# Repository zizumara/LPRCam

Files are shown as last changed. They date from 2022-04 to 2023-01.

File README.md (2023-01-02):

# LPRCam
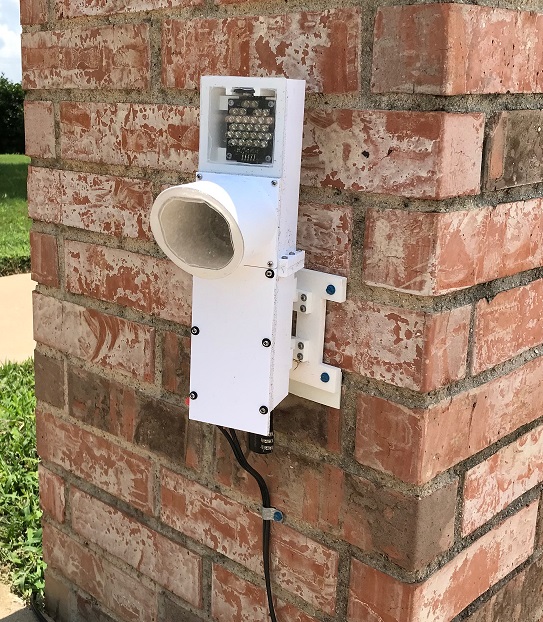
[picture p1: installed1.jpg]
Installed Camera


(2022-06-06 NOTE: UCTronics has modified the design of the Arducam 12.3 MP HQ camera with automatic IR-cut filter.  The new design requires the Bullseye O/S to be used, and the IR-cut filter interface now works differently.  Unfortunately, there isn't a distribution of openalpr for Bullseye.  You may be able to special order the older version of the camera from Arducam and continue to use Buster.  If anyone can figure out how to get this project updated for Bullseye, I'd like to hear from them.)

This project includes the software and hardware design for a DIY motion-activated Raspberry Pi security camera.  The Linux Motion application is used to detect motion and capture images.  The following hardware is used for this project:
* Raspberry Pi Zero W running Buster O/S
* Pi Zero W 6" camera ribbon cable (Amazon)
* Raspberry Pi 4 (for web server)
* Arducam 12.3 MP HQ camera with automatic IR-cut filter (www.arducam.com) -- photocell removed
* Arducam 12mm CS-Mount Lens with Manual Focus and Adjustable Aperture (Amazon)
* A custom IR illuminator (KiCAD files included)
* A custom ambient light sensor (KiCAD files included)
* A 3D-printable enclosure (STL files included) -- use white PETG filament
* A 5V 2.5A step-down voltage regulator (Pololu #2858)
* 2.1mm DC panel mount barrel jack (Adafruit #610) and plug
* CESFONJER Mini Locking Toggle Switch (Amazon)
* GIVERARE Combination Travel Cable Lock (Amazon)
* DEWENWILS 60W Outdoor Low Voltage Transformer (Amazon)
* Woods 55213143 16/2 Low Voltage Lighting Cable, 100-Feet (Amazon)
* Red and green LEDs with 330 Ohm current limiting resistors
* 26 AWG wiring with various Dupont connectors (KiCAD files included)
* Clear Lexan sheet 0.08x7.6x11 inch or similar dimensions (Amazon)
* Clear silicone waterproof sealant (Amazon)
* Silicone modified conformal coating (Amazon)
* 22 #3-48x1/2" steel screws (Fastenal or McMaster-Carr)
* 12 #3-48x1/16" steel screws  (Fastenal or McMaster-Carr)
* Microchip Pickit 4 programmer (for programming the custom light sensor)
* (Optional) Wireless Access Point (Amazon)

For nighttime operation, when the ambient light sensor registers light below a configured level, software enables the IR illuminator and switches in the IR-cut filter on the camera module.  The light level is used to select one of three different Motion configuration files which have mmalcam_control_params settings appropriate for daytime, twilight, and nighttime operation, respectively.  The light level is a time-averaged reading for which the width of the sampling window may be adjusted via the sensor I2C interface.

The camera box should be printed with white PETG filament to resist outdoor heat as well as heat generated by the IR illuminator and Pi Zero W.  All parts of the box should be given four coats of silicone modified conformal coating, both inside and out.  (WARNING: silicone modified conformal coating must be applied in an area with good ventilation.)  The Lexan covers for the camera shroud and IR array opening must be cut to fit from the Lexan sheet.  All seams must be filled with silicone sealant to produce a waterproof enclosure, including around the power jack.

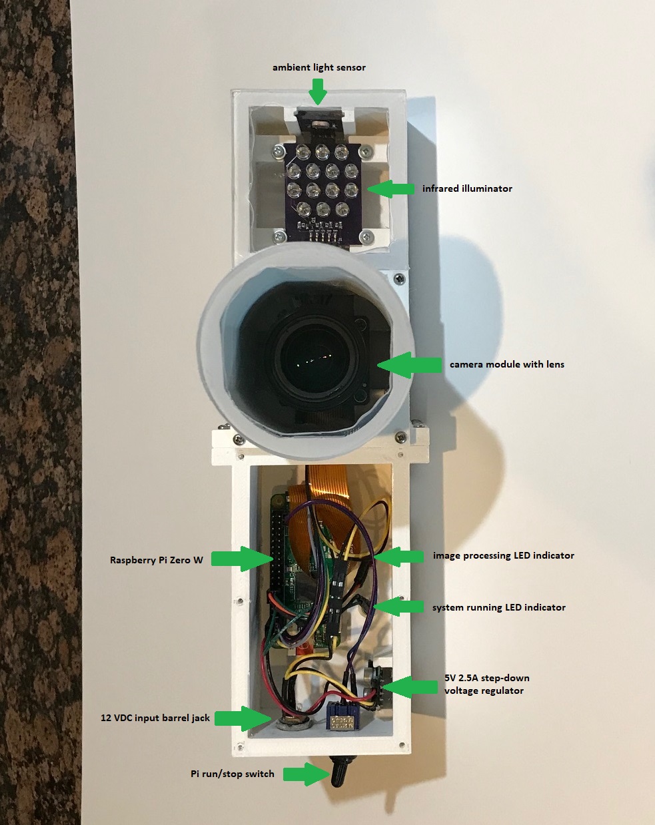
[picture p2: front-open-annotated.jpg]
Camera Box Interior


# Web Server

The files included in the /web directory provide everything needed to create a web server for reviewing captured images and license plate numbers.  The web server runs on a separate Raspberry Pi 4B.  If the web server is to be accessible from the Internet, it is strongly recommended that the security hardening procedures be followed in setup.txt.

During operation, captured files are periodically copied from the Pi Zero W to the web server via rsync.  A wireless access point may be needed if the camera box is not close to your wireless router.  The web server performs the CPU-intensive analysis of the captured images using OpenALPR to detect and read license plates.  The results are displayed on the web page, an example of which is shown below (for security reasons, plate numbers and actual camera location are blanked out in grey).

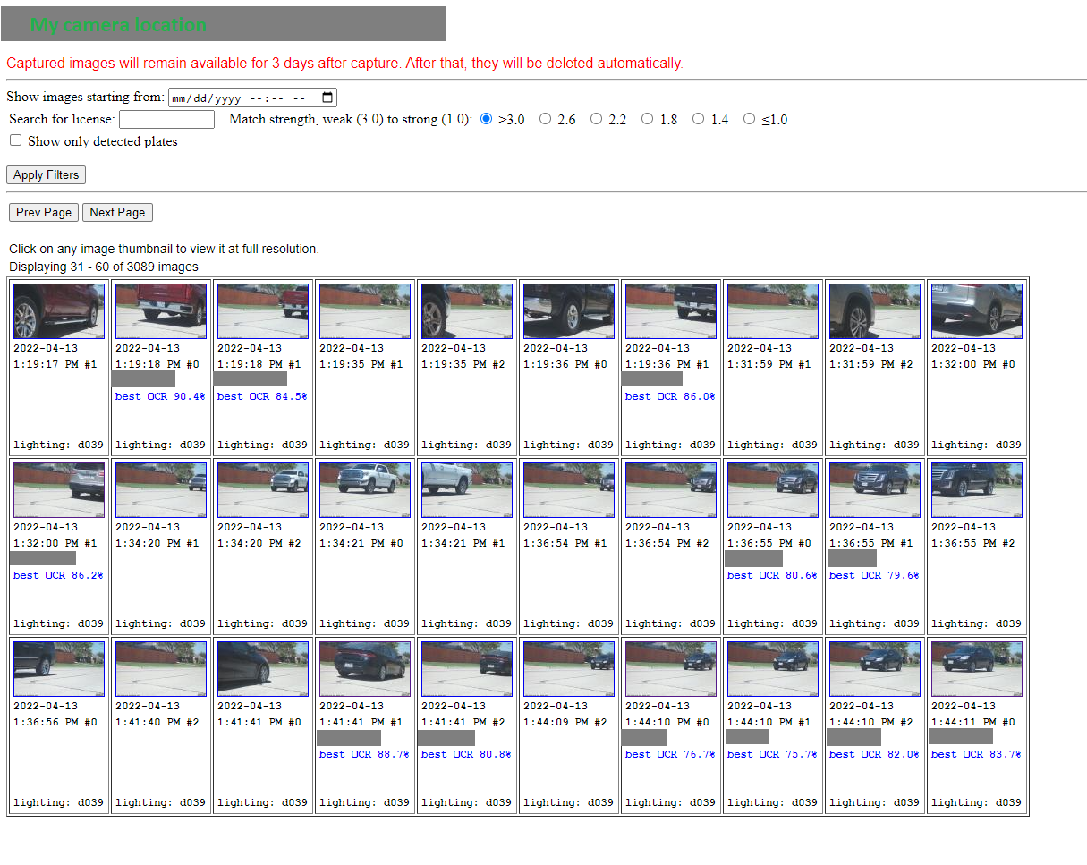
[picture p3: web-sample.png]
Web Page


For each captured image, a thumbnail is displayed with the date and time of capture and the lighting level at the bottom in format s###, where s is 'd' for day, 't' for day-twilight, 'u' for night-twilight, and 
'n' for night, and the 3-digit number represents the value read from the light sensor.  If a plate is detected by OpenALPR, the highest confidence plate number result is displayed below the capture date, along with the best confidence level of the optical character recognition (OCR) algorithm (0-100%).  A question mark (?) follows the plate number as a signal that this is the best guess by OpenALPR.  Users may click on any thumbnail to display the full resolution image on a new page.  On this page, the user may enter the actual license plate number so that it may be displayed on the main page in green followed by the text "** verified **".

The top of the main page has a filter section which may be used to limit the number of images displayed.

* Starting date: By default, all captured images are displayed regardless of capture date.  Setting the date and clicking Apply Filters can be used to limit the list to more recent images.
* Search for license: Enter license plate text in this box and click Apply Filters to find OpenALPR results similar to the text supplied.  Use the match strength radio buttons to set how close the match must be to the supplied text.
* Show only detected plates: Check this box and click Apply Filters to display only images for which OpenALPR has found a license plate.

The license plate search algorithm is optimized using OCR statistics gathered from hundreds of prior OpenALPR results that were each manually verified on the view full image page.  Entries made here are added to the OpenALPR .json files in the results directory.  Certain characters like 'B' may be misinterpreted by the OCR engine as '8', or 'D' may be misinterpreted as '4'.  Some characters, like 'I' may not be present at all on any license plate, but might be misidentified from a '1' or from an edge on the license plate.  The genalprstats.py module analyzes the contents of the results directory to determine the frequency at which characters are correctly or incorrectly identified.  The results of this analysis are stored in ocrstats.pickle and applied when the user performs a license plate search using a modified Wagner-Fischer algorithm to find the Levenshtein distance between the plate number entered and the plate numbers returned by OpenALPR.

The Levenshtein distance is defined as the smallest number of 1-character substitutions to convert one string into another.  The modifications to the Wagner-Fischer algorithm allow for the substitution value (normally 1) to be less than one depending on the frequency at which the OCR engine makes an error for the particular substitution. This modified Levenshtein distance can be set as the threshold to count an OpenALPR result as as match when performing a search.  The threshold for the search can be set using the radio buttons at the top of the main web page.  A modified Levenshtein distance of 3.0 or greater signifies a "weak" match, while a modified Levenshtein distance of 1.0 or less represents a "stong" match.

The ocrstats.pickle file in this archive are specific to the location at which testing was originally performed.  This may not be suitable for a different location, in which case a new file might be generated.  However, keep in mind that this requires a large number of plates to be manually verified to generate sufficient data for the analysis.  The existing ocrstats.pickle file was generated from approximately 1,000 analyzed plates, and a similar number is recommended for a new analysis.

# Performance

The following factors are the most significant in their effect on the performance of this system.

* Motion frame rate: The Motion application can capture about 1 to 2 frames per second under the given configuration.  This depends on image size and the processing power of the Raspberry Pi Zero W.  The current frame rate appears to be suitable for capturing at least one image of a license plate on a moving vehicle under most conditions.  The frame rate could be increased by reducing the image size or replacing the Pi Zero W with a Pi Zero 2 W.  However, increasing the rate at which images are captured may be detrimental to other performance factors.
* Image capture rate: The Motion application may experience false positives for detecting motion due to changing lighting conditions.  In particular, windy, partly cloudy days often produce hundreds or even thousands of additional images per day, as the changing cloud shadows often cause significant numbers of pixels in the image to change intensity.  The threshold parameter in motion_day.conf sets the number of changed pixels to trigger motion capture.
* Image transfer rate: Images are periodically transferred from the camera system to the web server for OpenALPR analysis using rsync.  If the image capture rate is large for an extended period, this can generate a large backlog of images to transfer, depending on the configured number of days to keep images in LPRCam.conf.  The result may be that the web server gets behind by several hours in analyzing images.  To reduce the number of image files to be synchronized, keep the number of days to keep files in LPRCam.conf low (no more than 1.0 days).  Note that the web server will keep images for three days, which is hardcoded in LPRserver.py.  The rsync bwlimit parameter is also hardcoded in LPRserver.py at 400 kbps to avoid overloading the wireless network, but may be increased or eliminated.
* ALPR masks: A portion of each image may be excluded from analysis by the OpenALPR application to reduce processing time for each image as defined by mask files.  Two mask files are provided in this archive, alpr-mask-1600x960.jpg and alpr-mask-800x480.jpg, which mask out the lower portion of the image where license plates are not expected to be found.  It may be necessary to replace or exclude these files.  Note that if renamed or excluded, the configuration files openalpr.defaults.1600x960 and openalpr.defaults.800x480 must be updated.
* ALPR processing: OpenALPR consumes considerable CPU resources in analyzing each image, which can result in a significant processing backlog.  Performance can be improved by reducing image dimensions.  Note that this must be done for all the motion configuration files and the OpenALPR mask files.

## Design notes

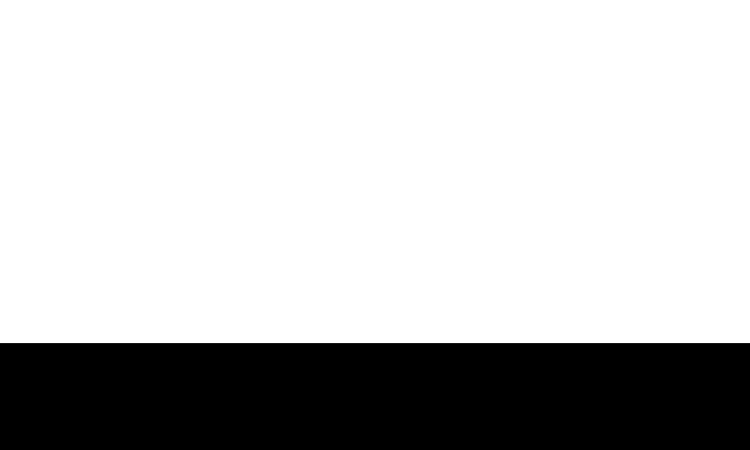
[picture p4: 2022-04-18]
web/openalpr-config/alpr-mask-800x480.jpg

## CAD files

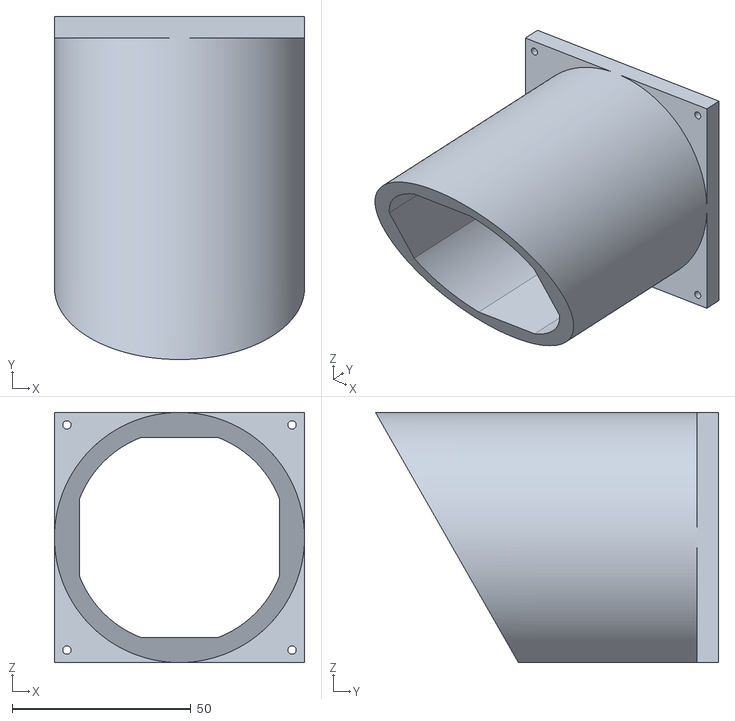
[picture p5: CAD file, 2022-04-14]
3D-printable-enclosure/camera shroud cyl.stl
70.0 x 96.0 x 70.0

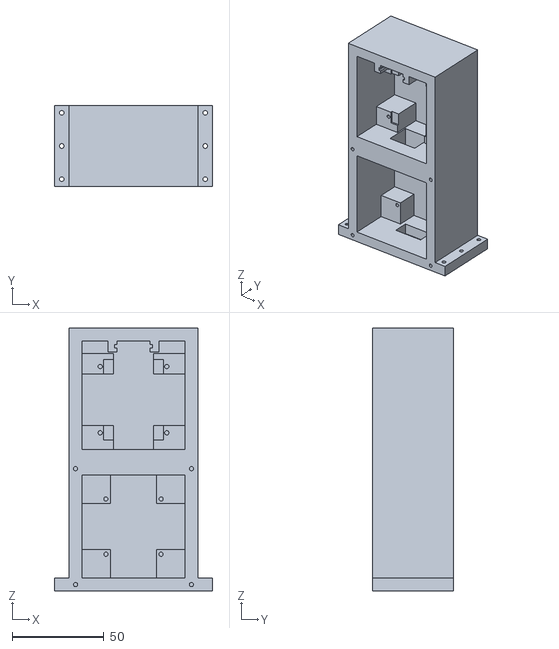
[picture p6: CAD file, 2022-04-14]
3D-printable-enclosure/camera box.stl
86.0 x 44.0 x 143.0

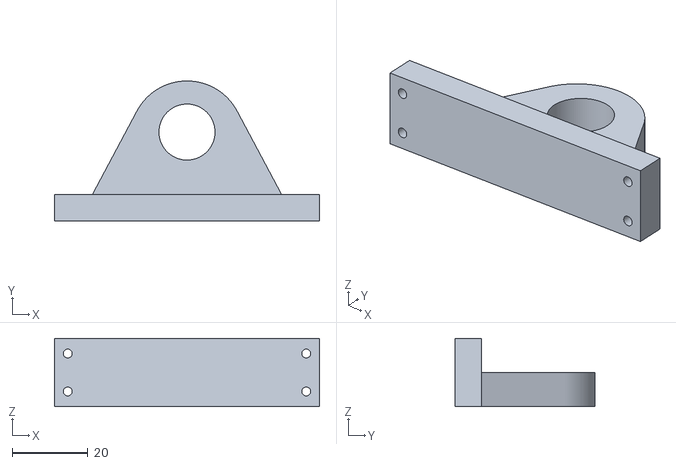
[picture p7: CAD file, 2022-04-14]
3D-printable-enclosure/CPU box mount.stl
70.0 x 37.0 x 18.0

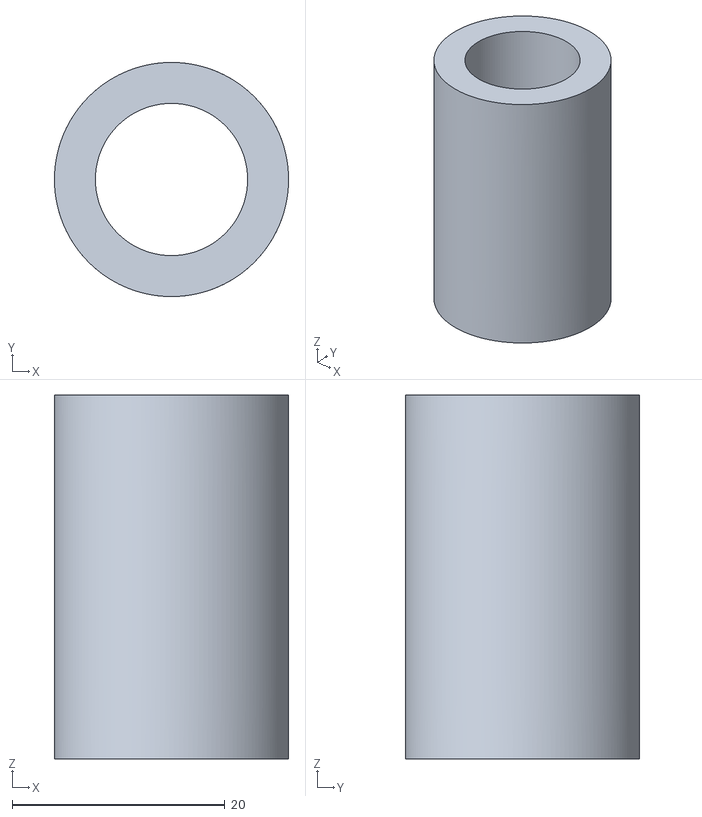
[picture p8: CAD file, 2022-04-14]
3D-printable-enclosure/mount sleeve.stl
22.0 x 22.0 x 34.2

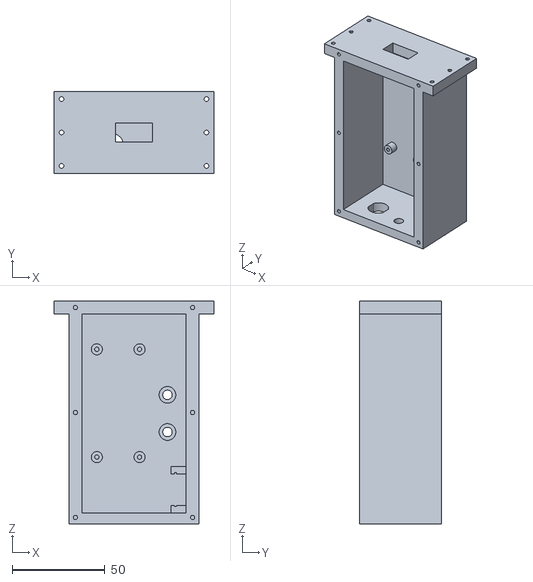
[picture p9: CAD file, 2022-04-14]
3D-printable-enclosure/CPU box.stl
86.0 x 44.0 x 120.0

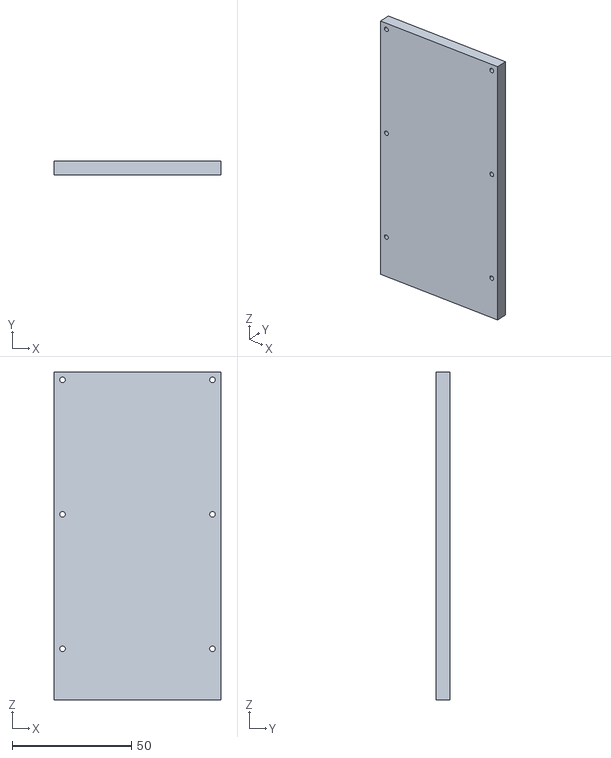
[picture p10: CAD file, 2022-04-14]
3D-printable-enclosure/CPU box cover.stl
70.0 x 6.00 x 137.8

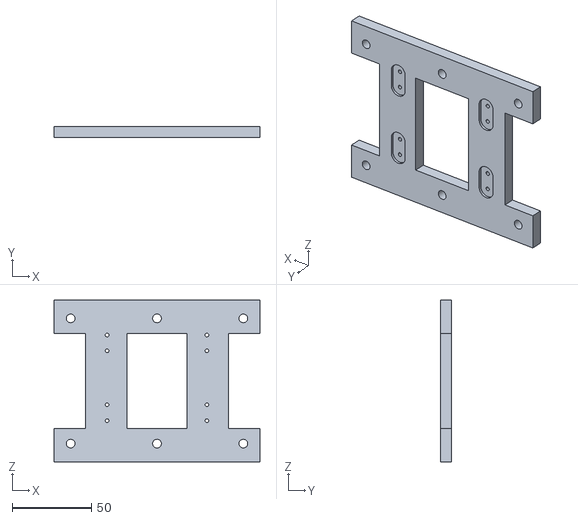
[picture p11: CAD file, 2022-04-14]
3D-printable-enclosure/base mount.stl
130.0 x 7.00 x 102.0

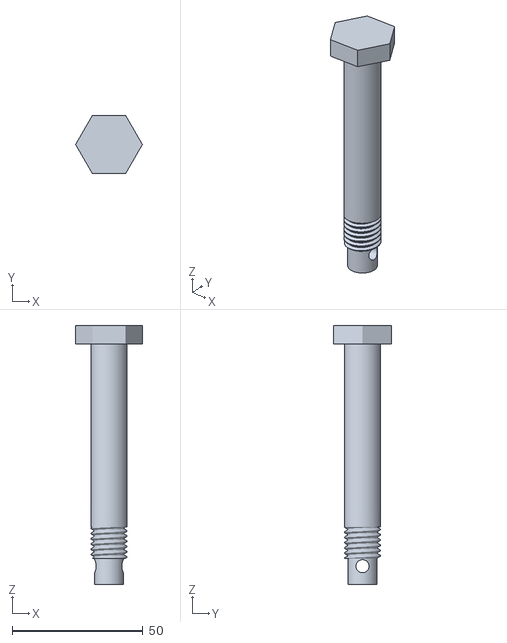
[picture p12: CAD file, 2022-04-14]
3D-printable-enclosure/mount bolt.stl
25.6 x 22.1 x 99.0

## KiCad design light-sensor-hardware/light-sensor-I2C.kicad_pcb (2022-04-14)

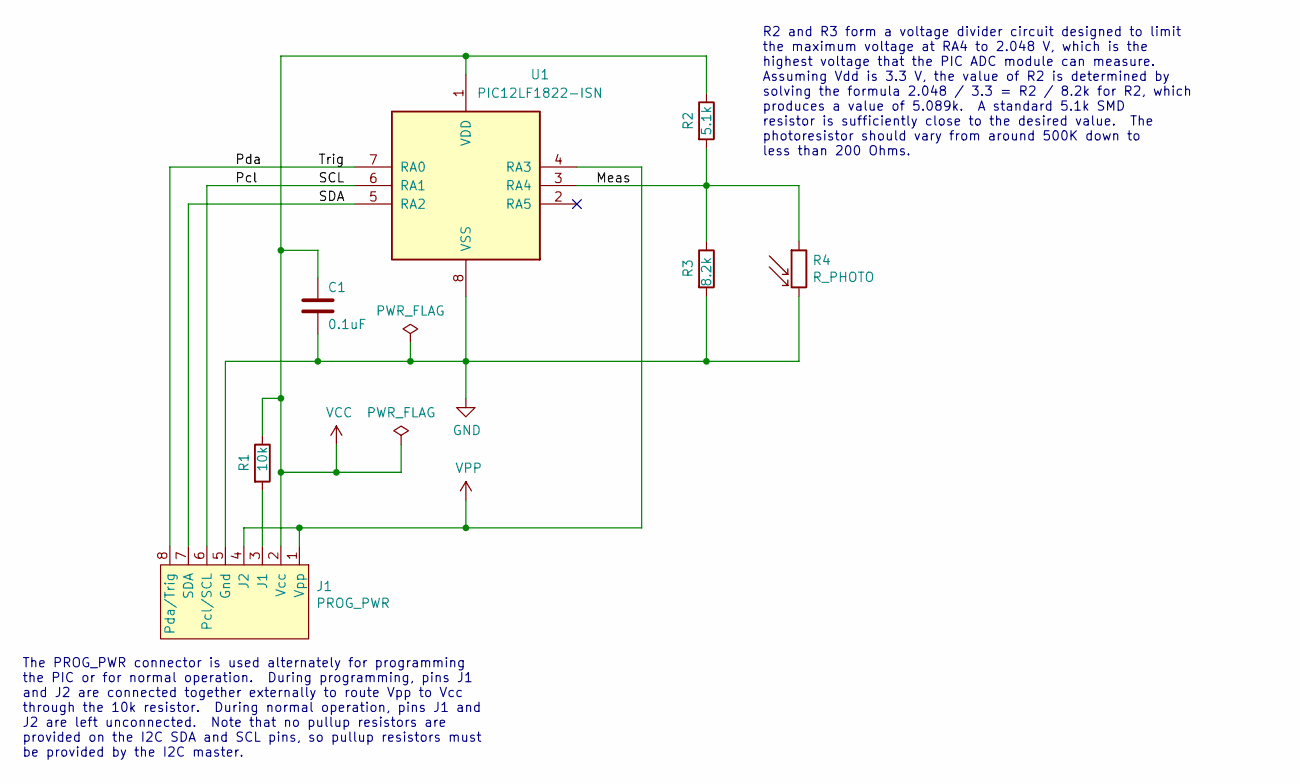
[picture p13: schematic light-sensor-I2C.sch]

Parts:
C1: 0.1uF; C_0805_2012Metric_Pad1.15x1.40mm_HandSolder
J1: PROG_PWR; PinSocket_2x04_P2.54mm_Horizontal
R1: 10k; R_0805_2012Metric_Pad1.15x1.40mm_HandSolder
R2: 5.1k; R_0805_2012Metric_Pad1.15x1.40mm_HandSolder
R3: 8.2k; R_0805_2012Metric_Pad1.15x1.40mm_HandSolder
R4: R_PHOTO; R_LDR_7x6mm_P5.1mm_Vertical
U1: PIC12LF1822-ISN; pic12lf1822-i&slash_sn

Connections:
/Meas: R2.2, R3.1, R4.1, U1.3 (RA4)
/Pcl: J1.6 (Pcl/SCL), U1.6 (RA1)
/Pda: J1.8 (Pda/Trig), U1.7 (RA0)
/SDA: J1.7 (SDA), U1.5 (RA2)
GND: C1.2, J1.5 (Gnd), R3.2, R4.2, U1.8 (VSS)
unnamed: J1.3 (J1), R1.2
VCC: C1.1, J1.2 (Vcc), R1.1, R2.1, U1.1 (VDD)
VPP: J1.1 (Vpp), J1.4 (J2), U1.4 (RA3)

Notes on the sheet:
R2 and R3 form a voltage divider circuit designed to limit the maximum voltage at RA4 to 2.048 V, which is the highest voltage that the PIC ADC module can measure. Assuming Vdd is 3.3 V, the value of R2 is determined by solving the formula 2.048 / 3.3 = R2 / 8.2k for R2, which produces a value of 5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
The PROG_PWR connector is used alternately for programming the PIC or for normal operation. During programming, pins J1 and J2 are connected together externally to route Vpp to Vcc through the 10k resistor. During normal operation, pins J1 and J2 are left unconnected. Note that no pullup resistors 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

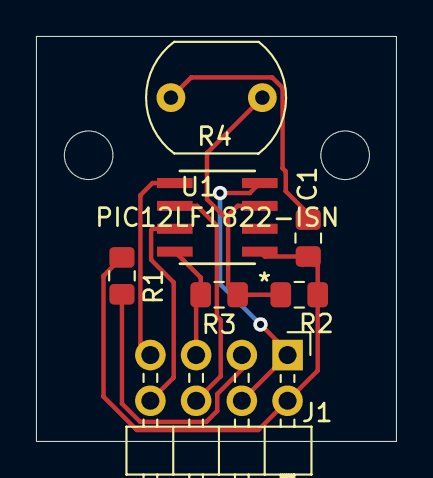
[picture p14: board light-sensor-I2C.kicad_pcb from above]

Board: 2 copper layers, 20.0 x 22.5 mm, 7 parts (0 on the bottom side), 8 nets.

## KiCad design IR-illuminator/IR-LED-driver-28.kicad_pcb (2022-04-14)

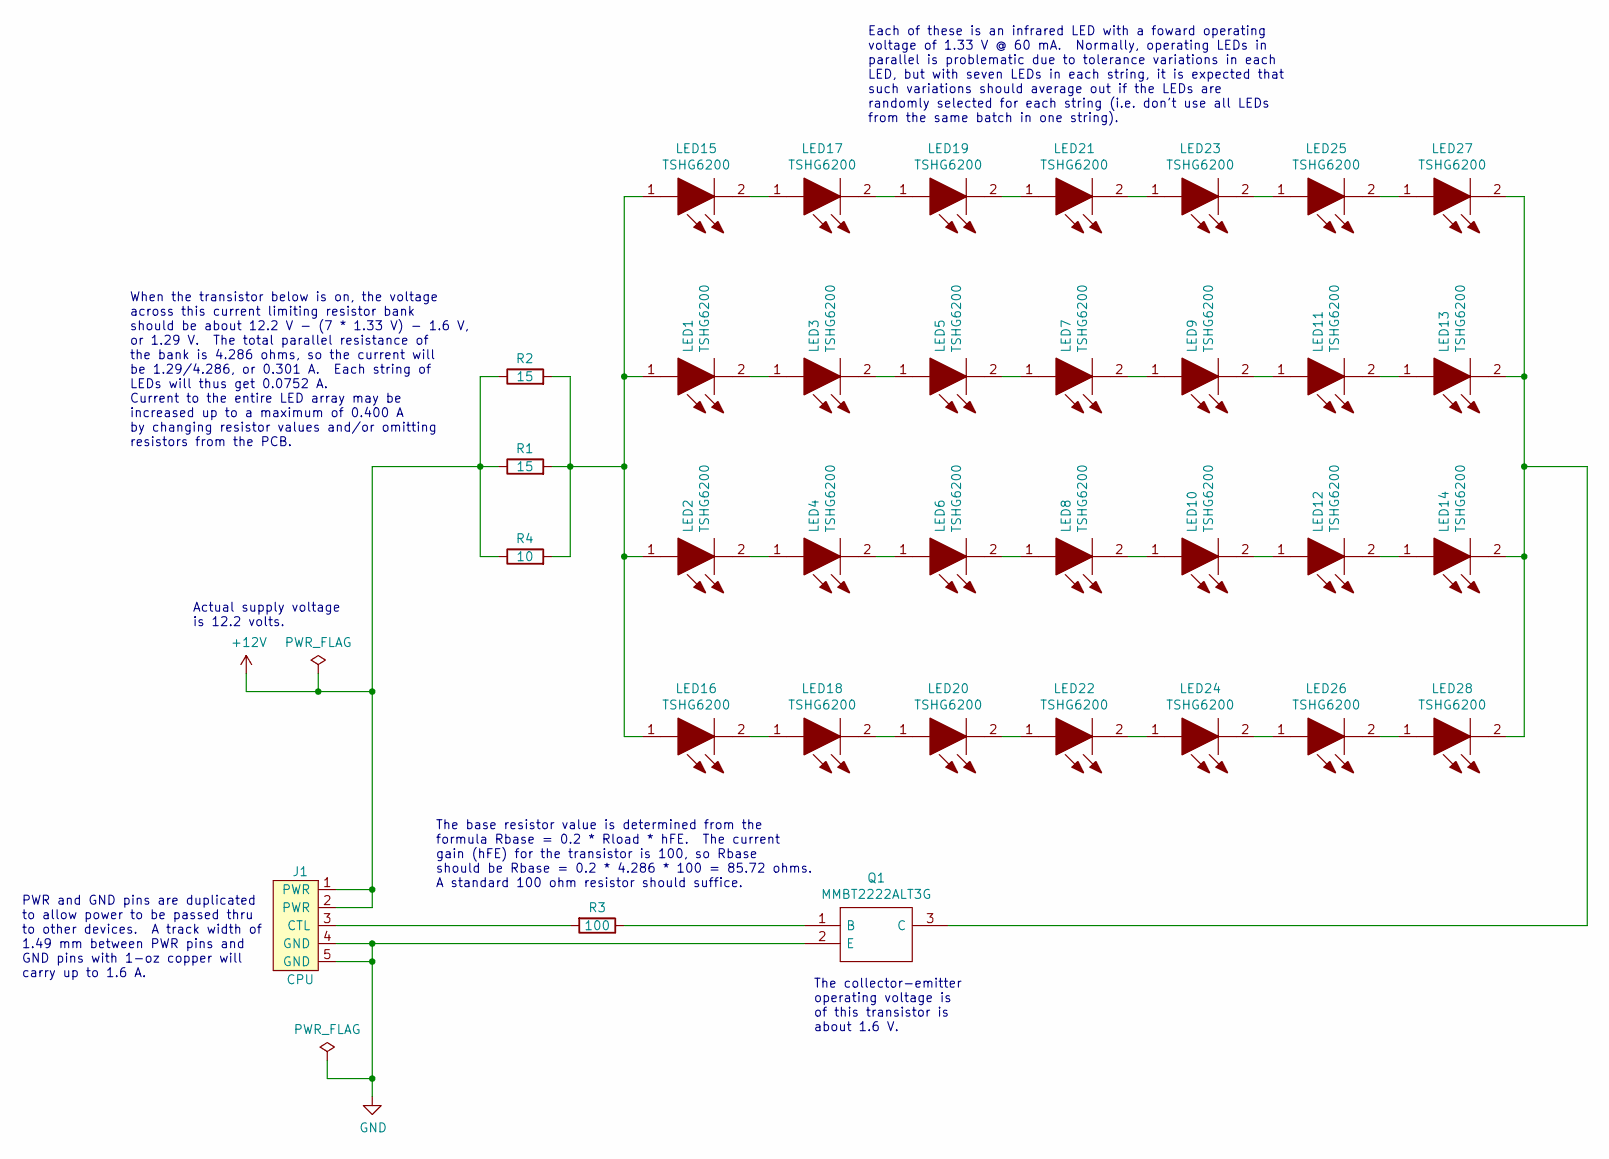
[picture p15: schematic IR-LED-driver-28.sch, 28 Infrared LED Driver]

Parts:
J1: CPU; PinHeader_1x05_P2.54mm_Horiz_SMD
LED1, LED2, LED3, LED4, LED5, LED6, LED7, LED8, LED9, LED10, LED11, LED12, LED13, LED14, LED15, LED16, LED17, LED18, LED19, LED20, LED21, LED22, LED23, LED24, LED25, LED26, LED27, LED28: TSHG6200; Mouser Part Number 782-TSHG6200
Q1: MMBT2222ALT3G; SOT96P237X111-3N; Mouser Part Number 863-MMBT2222ALT3G
R1, R2: 15; R_0805_2012Metric_Pad1.15x1.40mm_HandSolder
R3: 100; R_0805_2012Metric_Pad1.15x1.40mm_HandSolder
R4: 10; R_0805_2012Metric_Pad1.15x1.40mm_HandSolder

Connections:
+12V: J1.1 (PWR), J1.2 (PWR), R1.1, R2.1, R4.1
GND: J1.4 (GND), J1.5 (GND), Q1.2 (E)
unnamed: J1.3 (CTL), R3.2
unnamed: LED1.1, LED2.1, LED15.1, LED16.1, R1.2, R2.2, R4.2
unnamed: LED1.2, LED3.1
unnamed: LED2.2, LED4.1
unnamed: LED3.2, LED5.1
unnamed: LED4.2, LED6.1
unnamed: LED5.2, LED7.1
unnamed: LED6.2, LED8.1
unnamed: LED7.2, LED9.1
unnamed: LED8.2, LED10.1
unnamed: LED10.2, LED12.1
unnamed: LED9.2, LED11.1
unnamed: LED11.2, LED13.1
unnamed: LED12.2, LED14.1
unnamed: LED13.2, LED14.2, LED27.2, LED28.2, Q1.3 (C)
unnamed: LED15.2, LED17.1
unnamed: LED16.2, LED18.1
unnamed: LED17.2, LED19.1
unnamed: LED18.2, LED20.1
unnamed: LED19.2, LED21.1
unnamed: LED20.2, LED22.1
unnamed: LED21.2, LED23.1
unnamed: LED22.2, LED24.1
unnamed: LED23.2, LED25.1
unnamed: LED24.2, LED26.1
unnamed: LED25.2, LED27.1
unnamed: LED26.2, LED28.1
unnamed: Q1.1 (B), R3.1

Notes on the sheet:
The collector-emitter operating voltage is of this transistor is about 1.6 V.
Each of these is an infrared LED with a foward operating voltage of 1.33 V @ 60 mA. Normally, operating LEDs in parallel is problematic due to tolerance variations in each LED, but with seven LEDs in each string, it is expected that such variations should average out if the LEDs are randomly select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
When the transistor below is on, the voltage across this current limiting resistor bank should be about 12.2 V - (7 * 1.33 V) - 1.6 V, or 1.29 V. The total parallel resistance of the bank is 4.286 ohms, so the current will be 1.29/4.286, or 0.301 A. Each string of LEDs will thus get 0.0752 A. Curre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
Actual supply voltage is 12.2 volts.
The base resistor value is determined from the formula Rbase = 0.2 * Rload * hFE. The current gain (hFE) for the transistor is 100, so Rbase should be Rbase = 0.2 * 4.286 * 100 = 85.72 ohms. A standard 100 ohm resistor should suffice.
PWR and GND pins are duplicated to allow power to be passed thru to other devices. A track width of 1.49 mm between PWR pins and GND pins with 1-oz copper will carry up to 1.6 A.

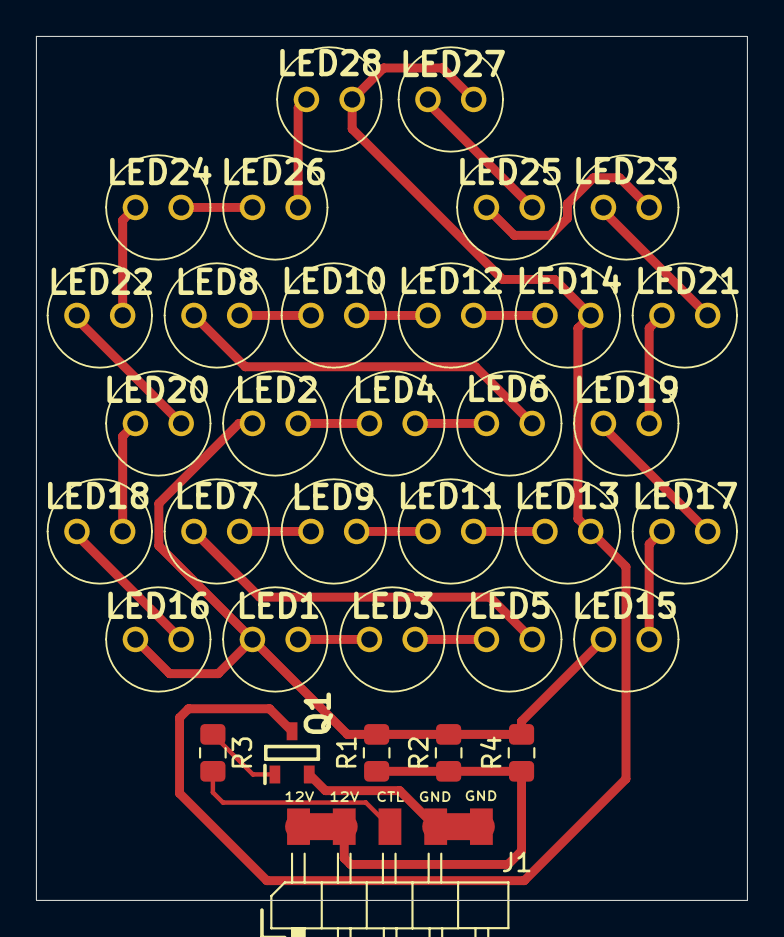
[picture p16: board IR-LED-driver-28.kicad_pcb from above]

Board: 2 copper layers, 39.5 x 48.0 mm, 34 parts (0 on the bottom side), 30 nets.

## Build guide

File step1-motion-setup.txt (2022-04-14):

This setup was copied from https://pimylifeup.com/raspberry-pi-webcam-server/comment-page-1/ and modified
specifically for still image capture only.

Update the Pi O/S:

   sudo apt-get update
   sudo apt-get upgrade

For convenient access from Windows via Remote Desktop, install xrdp:

   sudo apt-get install xrdp

(or install PuTTY to access the Pi command line only)

Connect the Pi camera and enable it via the desktop preferences menu or use the following:

   sudo raspi-config

Add the Pi camera as a v4l2 device to modules:

   sudo modprobe bcm2835-v4l2

(An alternate technique is to add bcm2835-v4l2 at the bottom of the /etc/modules file.)

Reboot the Pi for the above changes to take effect:

   sudo reboot

Install the packages needed by Motion:

   sudo apt install autoconf automake build-essential pkgconf libtool git libzip-dev libjpeg-dev gettext libmicrohttpd-dev 
      libavformat-dev libavcodec-dev libavutil-dev libswscale-dev libavdevice-dev default-libmysqlclient-dev libpq-dev 
      libsqlite3-dev libwebp-dev

Get the Motion deb file for Raspian Buster from GitHub and install it:

   sudo wget https://github.com/Motion-Project/motion/releases/download/release-4.3.1/pi_buster_motion_4.3.1-1_armhf.deb
   sudo dpkg -i pi_buster_motion_4.3.1-1_armhf.deb

Create and configure directories for pictures and movies:

   sudo mkdir /motion
   sudo chgrp motion /motion
   sudo chmod a+rwx /motion

Configure Motion (see motion-configuration.txt; use /motion as target_dir).

Disable the Motion daemon by editing /etc/default/motion and setting start_motion_daemon=no

Run the motion application:

   motion -c /etc/motion/motion.conf

Upon motion detection, the captured images will be stored in the /motion directory.  This directory needs to be 
purged periodically to prevent from consuming all disk space.  Application logging is directed to stderr.

RUNNING IN DAEMON MODE

The application can also be run automatically in daemon mode at boot up by setting start_motion_daemon=no in 
/etc/default/motion and setting daemon on in /etc/motion/motion.conf.  Whenever making changes to motion.conf, 
the service must be restarted as follows:

   sudo service motion restart

The motion service can be stopped using the following:

   sudo service motion stop

To determine if the motion service is running, use

   sudo service --status-all

and verify that motion is preceded by '[+]'.  If the service is not running, this will be '[-]'.

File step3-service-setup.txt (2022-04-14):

LPRCam Service Installation Instructions

These instructions assume that LPRCam.py is located in /home/pi/projects/LPRCam.

1. Copy LPRCam.sh to directory /usr/local/bin.

2. Make sure LPRCam.sh is executable with

      sudo chmod 755 /usr/local/bin/LPRCam.sh

3. Copy LPRCam.service to directory /lib/systemd/system.

4. Use the following to enable the service on startup.

      sudo systemctl enable LPRCam
      
5. To check status after startup, use

      sudo systemctl status LPRCam
   
   This should display status showing that LPRCam.service is loaded and 
   the status is "active (running)".

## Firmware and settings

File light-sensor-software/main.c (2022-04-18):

/*******************************************************************************
 * Light Sensor with I2C Interface
 * Created May 9, 2021
 * 
 * Overview:
 * This program runs on a PIC12LF1822 MCU and takes regular ADC samples of the
 * voltage across a CdS photocell, providing the readings across an I2C 
 * interface.  The circuit is designed such that complete darkness reads as
 * near the maximum ADC voltage of 2.048V and full brightness reads near 0V
 * (corresponding to 10-bit values of 1023 and 0, respectively).  The readings
 * are averaged on a sliding window basis, with the time width of the window
 * in seconds specified by the I2C master.  The time width of the window is
 * the amount of time that it takes for all prior measurements to be replaced
 * with new measurements.  The PIC provides a digital output that is set to 
 * high when a measurement level is equaled or exceeded.  The trigger level 
 * may be set by the I2C master.  All values communicated via the I2C 
 * interface occupy 2 bytes each in little endian order.  (Refer to I2C_slave.h
 * for I2C address and buffer offsets.)
 * 
 * Pin assignments: 
 *                                                                    weak
 *    function                           I/O   pin#  in/out  dig/ana  pullup
 * ----------------------------------------------------------------------------
 *    ICSPDAT/level trigger              RA0    7    output  digital  disabled
 *    ICSPCLK/I2C SCL                    RA1    6    input   digital  disabled
 *    I2C SDA                            RA2    5    input   digital  disabled
 *    MCLR/unused                        RA3    4    output  digital  disabled
 *    ADC measurement                    RA4    3    input   analog   disabled
 *    unused                             RA5    2    output  digital  disabled
 * 
 * Modules used:
 *    MSSP (I2C)
 *    ADC
 *    TIMER0
 */

// PIC12LF1822 Configuration Bit Settings
#pragma config FOSC = INTOSC    // Oscillator Selection (INTOSC oscillator: I/O function on CLKIN pin)
#pragma config WDTE = OFF       // Watchdog Timer Enable (WDT disabled)
#pragma config PWRTE = OFF      // Power-up Timer Enable (PWRT disabled)
#pragma config MCLRE = OFF      // MCLR Pin Function Select (MCLR/VPP pin function is digital input)
#pragma config CP = OFF         // Flash Program Memory Code Protection (Program memory code protection is disabled)
#pragma config CPD = OFF        // Data Memory Code Protection (Data memory code protection is disabled)
#pragma config BOREN = ON       // Brown-out Reset Enable (Brown-out Reset enabled)
#pragma config CLKOUTEN = OFF   // Clock Out Enable (CLKOUT function is disabled. I/O or oscillator function on the CLKOUT pin)
#pragma config IESO = OFF       // Internal/External Switchover (Internal/External Switchover mode is disabled)
#pragma config FCMEN = OFF      // Fail-Safe Clock Monitor Enable (Fail-Safe Clock Monitor is disabled)
#pragma config WRT = OFF        // Flash Memory Self-Write Protection (Write protection off)
#pragma config PLLEN = ON       // PLL Enable (4x PLL enabled)
#pragma config STVREN = ON      // Stack Overflow/Underflow Reset Enable (Stack Overflow or Underflow will cause a Reset)
#pragma config BORV = LO        // Brown-out Reset Voltage Selection (Brown-out Reset Voltage (Vbor), low trip point selected.)
#pragma config LVP = OFF        // Low-Voltage Programming Enable (High-voltage on MCLR/VPP must be used for programming)

#include <xc.h>
#include <pic12lf1822.h>
#include <stdint.h>
#include "timer_clock.h"
#include "I2C_slave.h"
#include "ADC.h"

#define NUM_SAMPLES        25    // number of samples in sliding average buffer
#define RFRSH_TO_SAMPLE_MS 41    // approximate number of milliseconds
                                 //   between samples to achieve refresh of 
                                 //   all samples in the sample buffer in 
                                 //   one second
// NOTE: NUM_SAMPLES * RFRSH_TO_SAMPLE_MS should be close to 1024.  This is 
//       because the sample clock period is 1.024 ms, and this allows the
//       sample refresh interval specified by the I2C master to accurately 
//       reflect the time to replace all samples in the sample buffer.

#define LEVEL_TRIGGER      LATAbits.LATA0

// Global data
uint16_t sampleBuffer[NUM_SAMPLES];
uint32_t sampleIntervalMs = RFRSH_TO_SAMPLE_MS;
uint32_t sampleSum = 0;
uint16_t triggerLevel = 0;

// Function prototypes
void sample_ADC(void);

// Interrupt handler wrapper
void __interrupt() main_ISR(void)
{
    I2C_slave_handler();
    TMR0_clock_handler();
}

void main(void)
{
    // Initialize system oscillator.
    OSCCONbits.SCS = OSCCON_SCS;     // Select clock source
    OSCCONbits.IRCF = OSCCON_IRCF;   // Select clock frequency
    OSCCONbits.SPLLEN = OSCCON_PLL;  // Set 4x PLL according to desired freq
    
    // Initialize port bits.
    WPUA   = 0b00000000;      // Disable all weak pull-ups (I2C master to 
                              // provide pull-ups on RA1 & RA2 I2C inputs)
    TRISA  = 0b00010110;      // Set RA0 as output for light level trigger
                              // Set RA1 & RA2 as inputs for I2C (SCL and SDA)
                              // Set RA3 & RA5 as unused outputs
                              // Set RA4 as input for ADC measurement
    ANSELA = 0b00010000;      // Set RA4 as analog for ADC measurement
                              // Set all others to digital
    LEVEL_TRIGGER = 0;        // set light level trigger to not triggered
    init_I2C();               // initialize and enable I2C interface
    init_ADC();               // initialize and enable ADC interface
    init_TMR0();              // initialize timer0 for sampling
    
    INTCONbits.PEIE = 1;      // enable peripheral interrupts
    INTCONbits.GIE  = 1;      // enable global interrupts
    
    
    // Initialize sample buffer and report first measurement.
    __delay_ms(100);          // extra setup time before 1st ADC read
    uint16_t sample1 = read_ADC();
    SSPBuffer[SSPIDX_MEAS_L] = sample1 & 0x00ff;
    SSPBuffer[SSPIDX_MEAS_H] = sample1 >> 8;
    SSPBuffer[SSPIDX_AVG_L] = sample1 & 0x00ff;
    SSPBuffer[SSPIDX_AVG_H] = sample1 >> 8;
    for (int i = 0; i < NUM_SAMPLES; i++)
    {
        sampleBuffer[i] = sample1;
        sampleSum += sample1;
    }
    
    // Set default trigger level to 511 and default refresh interval to 1 sec.
    uint16_t sampleRefreshSecReq = 1;
    SSPBuffer[SSPIDX_RFRSH_SEC_L] = 0x01;
    SSPBuffer[SSPIDX_RFRSH_SEC_H] = 0x00;
    triggerLevel = 511;
    SSPBuffer[SSPIDX_TRIG_L] = 0xff;
    SSPBuffer[SSPIDX_TRIG_H] = 0x01;

    while(1)
    {
        // When the sample clock expires, update the sample buffer with another 
        // ADC sample and restart the clock.
        if (TMR0_get_clock() > sampleIntervalMs)
        {
            TMR0_reset_clock();
            sample_ADC();
        }
        
        // Continuously check for I2C master updates to the sample refresh 
        // interval.  The requested value is in seconds.  Convert it to 
        // milliseconds for use with the sample clock.
        sampleRefreshSecReq = SSPBuffer[SSPIDX_RFRSH_SEC_H];
        sampleRefreshSecReq = (sampleRefreshSecReq << 8) + 
                              SSPBuffer[SSPIDX_RFRSH_SEC_L];
        if (sampleRefreshSecReq == 0)
        {
            sampleIntervalMs = RFRSH_TO_SAMPLE_MS;
        }
        else
        {
            sampleIntervalMs = RFRSH_TO_SAMPLE_MS * sampleRefreshSecReq;
        }
        
        // Continuously check for I2C master updates to the trigger level.
        triggerLevel = SSPBuffer[SSPIDX_TRIG_H];
        triggerLevel = (triggerLevel << 8) + SSPBuffer[SSPIDX_TRIG_L];
    }
}

// This function implements a sliding window summation of all ADC values read.
// On each call, read a new sample value from the ADC, subtract the oldest 
// sample value from the sum of all samples, and add the new sample value to 
// the sample sum, and replace the old sample in the sample buffer with the new
// sample.  This technique avoids having to add up all the sample values to 
// calculate an average every time a new sample is taken.  The average sample 
// value is calculated and written to the SSP buffer along with the current 
// sample value for collection by the I2C master.  The average is also compared
// to the trigger level set by the I2C master in the SSP buffer and the level 
// trigger output is set or cleared based on the comparison.
void sample_ADC(void)
{
    static uint8_t sampleIndex = 0;
    uint16_t newSample = 0;
    uint16_t triggerLevel = 0;
    uint16_t sampleAvg = 0;

    newSample = read_ADC();
    sampleSum -= sampleBuffer[sampleIndex];
    sampleSum += newSample;
    sampleBuffer[sampleIndex] = newSample;
    sampleIndex++;
    if (sampleIndex >= NUM_SAMPLES)
    {
        sampleIndex = 0;
    }
    sampleAvg = sampleSum / NUM_SAMPLES;
    triggerLevel = ((uint16_t)SSPBuffer[SSPIDX_TRIG_H] << 8)
                   + (uint16_t)SSPBuffer[SSPIDX_TRIG_L];
    if (sampleAvg >= triggerLevel)
    {
        LEVEL_TRIGGER = 1;
    }
    else
    {
        LEVEL_TRIGGER = 0;
    }
    SSPBuffer[SSPIDX_AVG_L] = sampleAvg & 0x00ff;
    SSPBuffer[SSPIDX_AVG_H] = sampleAvg >> 8;
    SSPBuffer[SSPIDX_MEAS_L] = newSample & 0x00ff;
    SSPBuffer[SSPIDX_MEAS_H] = newSample >> 8;
}

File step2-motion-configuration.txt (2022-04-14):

Detailed information on configuration options can be found at
https://motion-project.github.io/motion_config.html#vid_control_params

After installation, save a copy of the original /etc/motion/motion.conf file.  Then make the following changes.

daemon: on, off (default)
   purpose: run motion as a daemon
   recommendation: set to off

stream_localhost: off, on (default)
   purpose: limits the access to the stream to the localhost
   recommendation: set to off

movie_output: off, on (default)
   purpose: creates a movie file from the stream
   recommendation: set to off (not needed for this application and just slows down the Pi)

width: (default 640)
   purpose: sets the pixel width of each frame
   recommendation: explicitly set to 640 for Pi camera to be sure

height: (default 480)
   purpose: sets the pixel height of each frame
   recommendation: explicitly set to 480 for Pi camera to be sure

picture_output: off, first, best, on (default)
   purpose: determines whether and how to output image
   recommendation: set to on

target_dir: text
   purpose: sets the directory in which to output pictures, movies, and snapshots
   recommendation: set to /motion (refer to motion-setup.txt for more details)

smart_mask_speed: 0-10, default 0 (off)
   purpose: automatically filters out pixel changes in small areas of the image
   recommendation: set to 5 if windy conditions cause false triggers

lightswitch_percent: 0-100, default 0 (off)
   purpose: suppresses motion detection when greater than this percentage of pixels change
   recommendation: may be needed for sudden illumination changes from headlights or clouds

lightswitch_frames: 1-1000, default 5
   purpose: number of frames to ignore when lightswitch triggers
   recommendation: tune if necessary

minimum_motion_frames: 1-1000, default 1
   purpose: number of frames tested for motion before motion event triggers
   recommendation: increase to 2-5 if too many false triggers

minimum_frame_time: 0-2147483647, default 0 (disabled - use framerate)
   purpose: minimum number of seconds between capturing picture frames
   recommendation: set to 1?

framerate: 2-100, default 15
   purpose: if minimum_frame_time set to 0, sets number of picture captures per second
   recommendation:  set to 2?

text_changes: on, off (default)
   purpose: overlay image with text indicating number of pixels changed from reference image
   recommendation: set to on

noise_tune: off, on (default)
   purpose: automatically adjust noise threshold to filter out camera noise
   recommendation: leave at default (on)

noise_level: 1-255; default 32
   purpose: manually sets camera noise threshold when noise_tune is off
   recommendation: use if camera noise is apparent in pictures

threshold: 1-2147483647, default 1500
   purpose: sets minimum number of pixels changed from reference image to trigger motion
   recommendation: increase if too many false triggers

threshold_tune: on, off (default)
   purpose: when on, continuously adjusts threshold for declaring motion (ignores threshold)
   recommendation: set to on if changed pixels is regularly above threshold for false triggers

vid_control_params: text, up to 4095 chars
   purpose: issues control parameters to camera (brightness, white level, etc.)
   recommendation: may be useful for adjusting camera settings

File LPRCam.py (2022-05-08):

#!/usr/bin/python3
# LPRcam.py

"""
This program operates a street security camera and captures images using
the Motion application.  It also reads the current light level from a
custom light sensor, switches an IR illuminator on/off, and controls
an IR-cut filter on the camera.
"""

import sys, subprocess, logging, time, json, re, Sun, datetime
import RPi.GPIO as GPIO
import smbus
from os import path, _exit, listdir, scandir
from pathlib import Path
from datetime import timedelta

MAX_PCT_DISK_USED  = 90    # if % disk used greater than this, exit program

PIN_RUNNING    = 16   # GPIO output pin connected to LED showing running status
PIN_PROCESSING = 15   # GPIO output pin connected to LED showing processing status
PIN_IR_LED_ON  = 11   # GPIO output pin connected to IR LED array transistor
PIN_IR_CUT_OFF = 33   # GPIO output pin connected to camera IR-cut filter

# I2C buffer offsets for interface to light meter.
I2C_AVG_L       = 0   # time-averaged light reading
I2C_AVG_H       = 1
I2C_MEAS_L      = 2   # instantaneous light reading
I2C_MEAS_H      = 3
I2C_RFRSH_SEC_L = 4   # number of seconds to refresh sliding window average
I2C_RFRSH_SEC_H = 5
I2C_TRIG_L      = 6   # threshold light reading for trigger signal (not used)
I2C_TRIG_H      = 7

I2C_BUFF_SIZE   = 8
I2C_ADDR = 0x30       # I2C address of light meter
REFRESH_SEC = 600     # seconds to refresh light level sliding average window

installDir             = '/home/pi/projects/LPRCam/'
motionImageDir         = '/motion'
dayMotionCfgFilePath   = '/home/pi/projects/LPRCam/motion_day.conf'
dayTwiMotionCfgFilePath  = '/home/pi/projects/LPRCam/motion_day_twilight.conf'
nightTwiMotionCfgFilePath  = '/home/pi/projects/LPRCam/motion_night_twilight.conf'
nightMotionCfgFilePath = '/home/pi/projects/LPRCam/motion_night.conf'
rtdataFilePath         = '/usr/share/openalpr/runtime_data'
coords = {'longitude' : -97.23, 'latitude' : 32.81 }

timeNextReport   = time.time()
startTime        = time.time()

def timestamp():
    return time.strftime('%Y-%b-%d %H:%M:%S')

def isTimeForStatus(reportPeriodSecs):
    """
    Checks current time and determines whether it is at or past time to create a
    status report.
    """
    global timeNextReport
    isItTime = False
    timeNow = time.time()
    if timeNow >= timeNextReport:
        isItTime = True
        timeNextReport = timeNow + reportPeriodSecs
    return isItTime

def getCPUTemp():
    """
    Returns the processor temperature in Celcius degrees as a string and as a
    floating point value (2-tuple).  If unable to get the temperature, return
    ('unknown', 0.0).  If unable to parse the result as a floating point value,
    return the string from the system with '(bad)' appended to the string.
    """
    cmd = ['/opt/vc/bin/vcgencmd', 'measure_temp']
    proc = subprocess.run(cmd, capture_output=True, text=True)
    match = re.search("temp=(.*)'C", proc.stdout)
    tempCPU = 0.0
    tempCPUStr = 'unknown'
    if match != None:
        tempCPUStr = match.group(1)
        try:
            tempCPU = float(tempCPUStr)
        except:
            tempCPUStr = tempCPUStr + '(bad)'

    return (tempCPUStr, tempCPU)

def getDiskPctUsed():
    """
    Returns percent of storage space used on the SD card.
    """
    cmd = ['df', '-h', '/']
    proc = subprocess.run(cmd, capture_output=True, text=True)
    match = re.search(".+\n\S+\s+\S+\s+\S+\s+\S+\s+(\S+)%", proc.stdout)
    pctUsed = 0
    if match != None:
        pctUsedStr = match.group(1)
        try:
            pctUsed = int(pctUsedStr)
        except:
            logging.info(f'{timestamp()} getDiskPctUsed() - Cannot convert "{pctUsedStr}" to int.')
            pctUsed = 0
    else:
        logging.info(f'{timestamp()} getDiskPctUsed() - Cannot find % disk used in df output:')
        logging.info(pctUsedStr)

    return pctUsed

def stageMotionImages(motionDir, processDir, diagDir, dayTwilightNight, lightLevel):
    """
    Check the Motion output directory for new images.  Move all of the image files
    found to the image processing directory, adding a suffix to the file name which
    indicates whether it is currently day, day-twilight, night-twilight, or night 
    and the current light level.
    Returns: imagesMoved - number of motion images moved to processing
    """
    illumID = 'd'
    if dayTwilightNight == 'day':
        illumID = 'd'
    elif dayTwilightNight == 'day-twilight':
        illumID = 't'
    elif dayTwilightNight == 'night-twilight':
        illumID = 'u'
    elif dayTwilightNight == 'night':
        illumID = 'n'
    imgSuffix = f'{illumID}{lightLevel:03d}'
    pathIter = Path(motionDir)
    motionImagePaths = [str(file) for file in pathIter.glob('*.jpg') if not str(file).endswith('m.jpg')]
    imagesMoved = 0
    for motionImagePath in motionImagePaths:
        procFileName = path.basename(motionImagePath).replace('.jpg', f'-{imgSuffix}.jpg')
        procFilePath = path.join(processDir, procFileName)
        proc = subprocess.run(['mv', motionImagePath, procFilePath])
        motionDiagPath = motionImagePath.replace('.jpg', 'm.jpg')
        imagesMoved += 1
        if path.exists(motionDiagPath):
            diagFileName = path.basename(motionDiagPath).replace('.jpg', f'-{imgSuffix}.jpg')
            diagFilePath = path.join(diagDir, diagFileName)
            proc = subprocess.run(['mv', motionDiagPath, diagFilePath])
    if imagesMoved > 0:
        print(f'{timestamp()} {imagesMoved} motion image files moved to processing directory.')

    return imagesMoved

def getOldestImage(imageDir):
    """
    For the given motion image directory, find and return the oldest image file, its matching
    diagnostic image (if any), and the number of image files in the directory (excluding
    diagnostic images).
    """
    oldestCaptureImage = None
    oldestDiagImage = None
    pathIter = Path(imageDir)
    imageFiles = [str(file) for file in pathIter.glob('*.jpg') if not str(file).endswith('m.jpg')]
    imagesByAge = sorted(imageFiles)
    imageCount = len(imagesByAge)
    if imageCount > 0:
        oldestCaptureImage = imagesByAge[0]
        diagFile = oldestCaptureImage.replace('.jpg', 'm.jpg')
        if path.exists(diagFile):
            oldestDiagImage = diagFile

    return (oldestCaptureImage, oldestDiagImage, imageCount)
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

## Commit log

2022-04-16 Create README.md
    This project includes the software and hardware design for DIY Raspberry Pi based security camera. The Linux Motion application is used to detect motion and capture images, and additional custom hard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
2022-06-06 Update README.md with note about Arducam camera changes and compatibility.
2024-04-20 Added camera focus testing code

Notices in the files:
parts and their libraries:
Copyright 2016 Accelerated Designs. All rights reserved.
